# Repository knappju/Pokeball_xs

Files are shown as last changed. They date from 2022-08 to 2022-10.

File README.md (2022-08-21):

# __Pokeball_xs__
## __Project Info__

__Created:__                        August 10, 2022

__Project Version:__                v 0.0.0.2  

__Stable Branch:__                  master

### __Code__
* __IDE:__ MPLAB X IDE v5.50

__Last Release Date:__              August 21, 2022  
__Last Stable Release:__            v 0.0.0.2 

### __ECAD__
* __CAD:__ KiCAD v6.0

__Last Release Date:__              August 21, 2022  
__Last Stable Release:__            v 0.0.0.2

## Versioning

For the versions available, see the [tags on this repository](https://github.com/knappju/Pokeball_xs/commits/master). 
## Authors

* **Justin Knapp** - *Circuit Design, PCB Design, Code, Mechanical Design*

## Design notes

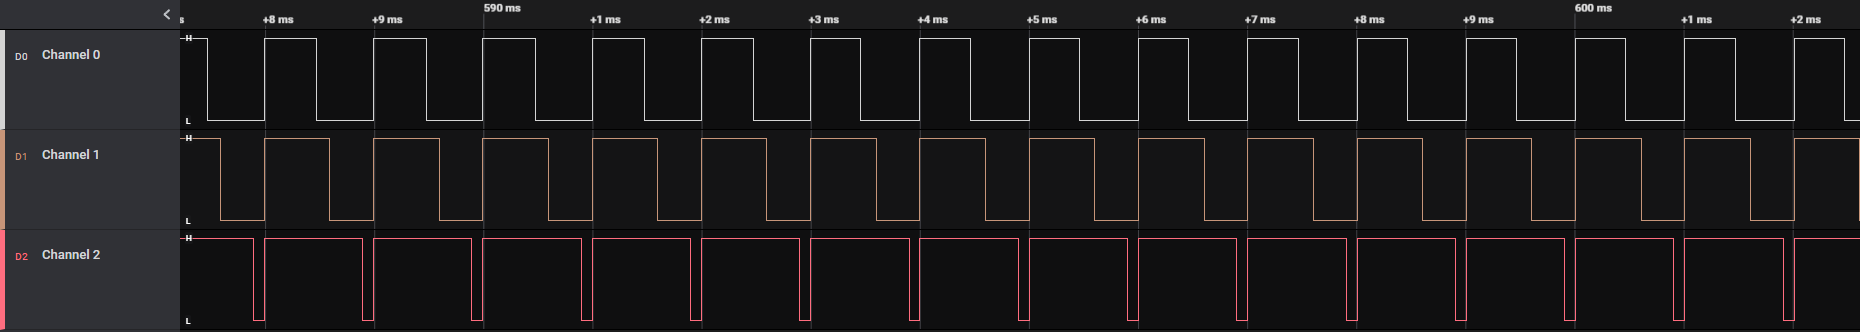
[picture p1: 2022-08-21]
Photos/v0.0.0.2_PWM_proof.PNG

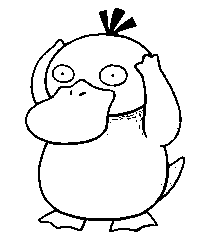
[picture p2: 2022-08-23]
Photos/psyduck.bmp

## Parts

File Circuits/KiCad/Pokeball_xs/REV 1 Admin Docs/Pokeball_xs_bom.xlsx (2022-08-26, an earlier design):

Source: | C:\Users\JustinK\Desktop\Pokeball_xs\Circuits\KiCad\Pokeball_xs\Pokeball_xs.kicad_sch
Date: | 2022-08-25 11:54
Tool: | Eeschema (6.0.5)
Generator: | C:\Program Files\KiCad\6.0\bin\scripting\plugins/bom_csv_grouped_by_value.py
Component Count: | 28
Individual Components:
Item | Qty | Reference(s) | Value | LibPart | Footprint
 |  | C1 | 0.1uF | Pokeball_xs-rescue:CP1_Small-Device | Capacitor_SMD:C_0603_1608Metric
 |  | C2 | 4.7uF | Pokeball_xs-rescue:CP1_Small-Device | Capacitor_SMD:C_0603_1608Metric
 |  | C3 | 0.1uF | Pokeball_xs-rescue:CP1_Small-Device | Capacitor_SMD:C_0603_1608Metric
 |  | C4 | 22uF | Pokeball_xs-rescue:CP1_Small-Device | Capacitor_SMD:C_0603_1608Metric
 |  | C5 | 1uF | Pokeball_xs-rescue:CP1_Small-Device | Capacitor_SMD:C_0603_1608Metric
 |  | C6 | 4.7uF | Pokeball_xs-rescue:CP1_Small-Device | Capacitor_SMD:C_0603_1608Metric
 |  | D1 | 40V 500mA | Device:D_Schottky | Diode_SMD:D_SOD-123
 |  | H1 | MountingHole | Mechanical:MountingHole | MountingHole:MountingHole_4.3mm_M4
 |  | H2 | MountingHole | Mechanical:MountingHole | MountingHole:MountingHole_4.3mm_M4
 |  | H3 | MountingHole | Mechanical:MountingHole | MountingHole:MountingHole_4.3mm_M4
 |  | H4 | MountingHole | Mechanical:MountingHole | MountingHole:MountingHole_4.3mm_M4
 |  | J1 | Conn_01x05 | Connector_Generic:Conn_01x05 | Connector_PinHeader_1.00mm:PinHeader_1x05_P1.00mm_Vertical
 |  | J2 | USB_B_Micro | Connector:USB_B_Micro | Connector_USB:USB_Micro-AB_Molex_47590-0001
 |  | J3 | Conn_01x06 | Connector_Generic:Conn_01x06 | Connector_PinHeader_1.00mm:PinHeader_1x06_P1.00mm_Vertical
 |  | J4 | Battery | Connector:Conn_01x02_Female | Connector_PinSocket_2.54mm:PinSocket_1x02_P2.54mm_Vertical
 |  | Q1 | 60V 170mA | Device:Q_PMOS_GSD | Package_TO_SOT_SMD:TSOT-23
 |  | R1 | 4.7k | Device:R_Small_US | Resistor_SMD:R_0603_1608Metric
 |  | R2 | 100 | Device:R_Small_US | Resistor_SMD:R_0603_1608Metric
 |  | R3 | 56 | Device:R_Small_US | Resistor_SMD:R_0603_1608Metric
 |  | R4 | 24 | Device:R_Small_US | Resistor_SMD:R_0603_1608Metric
 |  | R5 | 24 | Device:R_Small_US | Resistor_SMD:R_0603_1608Metric
 |  | R6 | 100 | Device:R_Small_US | Resistor_SMD:R_0603_1608Metric
 |  | R7 | 4.7k | Device:R_Small_US | Resistor_SMD:R_0603_1608Metric
 |  | R8 | 10k | Device:R_Small_US | Resistor_SMD:R_0603_1608Metric
 |  | R9 | 10k | Device:R_Small_US | Resistor_SMD:R_0603_1608Metric
 |  | U1 | PIC12LF1571T-I_SN | Pokeball_xs-rescue:PIC12LF1571T-I_SN-PIC12LF1571T-I-SN | PIC12LF1571T-I_SN:PIC12LF1571T-I&slash_SN
 |  | U2 | MCP1754ST-3302E_DB | Pokeball_xs-rescue:MCP1754ST-3302E_DB-MCP1754ST-3302E-DB | MCP1754ST-3302E_DB:MCP1754ST-3302E&slash_DB
 |  | U3 | MCP73831-2-OT | Battery_Management:MCP73831-2-OT | Package_TO_SOT_SMD:SOT-23-5
Collated Components:
Item | Qty | Reference(s) | Value | LibPart | Footprint | Cost per 1 | Total Cost | Have? | Ordered | Status
1 | 2 | C1, C3 | 0.1uF | Pokeball_xs-rescue:CP1_Small-Device | Capacitor_SMD:C_0603_1608Metric | 0.0125 | 0.025 | FALSE | TRUE | PENDING
2 | 2 | C2, C6 | 4.7uF | Pokeball_xs-rescue:CP1_Small-Device | Capacitor_SMD:C_0603_1608Metric | 0.0246 | 0.0492 | FALSE | TRUE | PENDING
3 | 1 | C4 | 22uF | Pokeball_xs-rescue:CP1_Small-Device | Capacitor_SMD:C_0603_1608Metric | 0.133 | 0.133 | FALSE | TRUE | PENDING
4 | 1 | C5 | 1uF | Pokeball_xs-rescue:CP1_Small-Device | Capacitor_SMD:C_0603_1608Metric | 0.0146 | 0.0146 | FALSE | TRUE | PENDING
5 | 1 | D1 | 40V 500mA | Device:D_Schottky | Diode_SMD:D_SOD-123 | 0.177 | 0.177 | TRUE | FALSE | GOOD
6 | 4 | H1, H2, H3, H4 | MountingHole | Mechanical:MountingHole | MountingHole:MountingHole_4.3mm_M4 | 0 | 0 | FALSE | FALSE | NEEDS ORDERING
7 | 1 | J1 | Conn_01x05 | Connector_Generic:Conn_01x05 | Connector_PinHeader_1.00mm:PinHeader_1x05_P1.00mm_Vertical | 0 | 0 | FALSE | FALSE | NEEDS ORDERING
8 | 1 | J2 | USB_B_Micro | Connector:USB_B_Micro | Connector_USB:USB_Micro-AB_Molex_47590-0001 | 0.86 | 0.86 | FALSE | TRUE | PENDING
9 | 1 | J3 | Conn_01x06 | Connector_Generic:Conn_01x06 | Connector_PinHeader_1.00mm:PinHeader_1x06_P1.00mm_Vertical | 0 | 0 | FALSE | FALSE | NEEDS ORDERING
10 | 1 | J4 | Battery | Connector:Conn_01x02_Female | Connector_PinSocket_2.54mm:PinSocket_1x02_P2.54mm_Vertical | 0 | 0 | FALSE | FALSE | NEEDS ORDERING
11 | 1 | Q1 | 60V 170mA | Device:Q_PMOS_GSD | Package_TO_SOT_SMD:TSOT-23 | 0.343 | 0.343 | TRUE | FALSE | GOOD
12 | 2 | R1, R7 | 4.7k | Device:R_Small_US | Resistor_SMD:R_0603_1608Metric | 0.0394 | 0.0788 | FALSE | TRUE | PENDING
13 | 2 | R2, R6 | 100 | Device:R_Small_US | Resistor_SMD:R_0603_1608Metric | 0.0184 | 0.0368 | FALSE | TRUE | PENDING
14 | 1 | R3 | 56 | Device:R_Small_US | Resistor_SMD:R_0603_1608Metric | 0.05 | 0.05 | FALSE | TRUE | PENDING
15 | 2 | R4, R5 | 24 | Device:R_Small_US | Resistor_SMD:R_0603_1608Metric | 0.05 | 0.1 | FALSE | TRUE | PENDING
16 | 2 | R8, R9 | 10k | Device:R_Small_US | Resistor_SMD:R_0603_1608Metric | 0.0184 | 0.0368 | FALSE | TRUE | PENDING
17 | 1 | U1 | PIC12LF1571T-I_SN | Pokeball_xs-rescue:PIC12LF1571T-I_SN-PIC12LF1571T-I-SN | PIC12LF1571T-I_SN:PIC12LF1571T-I&slash_SN | 0.79 | 0.79 | TRUE | FALSE | GOOD
18 | 1 | U2 | MCP1754ST-3302E_DB | Pokeball_xs-rescue:MCP1754ST-3302E_DB-MCP1754ST-3302E-DB | MCP1754ST-3302E_DB:MCP1754ST-3302E&slash_DB | 0.84 | 0.84 | TRUE | FALSE | GOOD
19 | 1 | U3 | MCP73831-2-OT | Battery_Management:MCP73831-2-OT | Package_TO_SOT_SMD:SOT-23-5 | 0.76 | 0.76 | TRUE | FALSE | GOOD
 |  |  |  |  |  |  | 4.2942

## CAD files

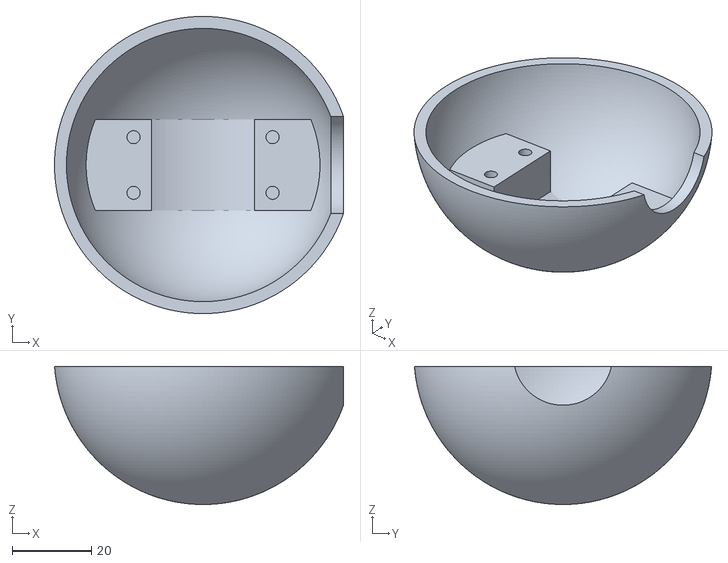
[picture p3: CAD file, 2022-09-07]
Mechanical/Bottom/bottomR1.stl
72.8 x 74.8 x 34.8

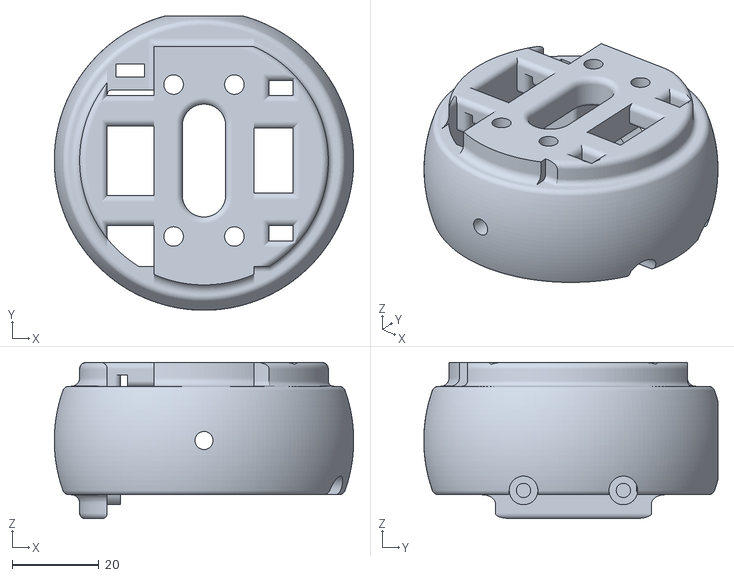
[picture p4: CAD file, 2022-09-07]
Mechanical/CenterHousing/CenterHousingR1.stl
69.0 x 67.7 x 36.0

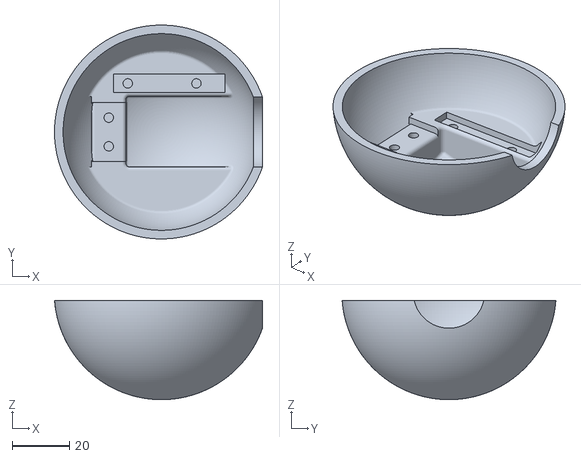
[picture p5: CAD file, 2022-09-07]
Mechanical/Top/top.stl
72.8 x 74.8 x 34.8

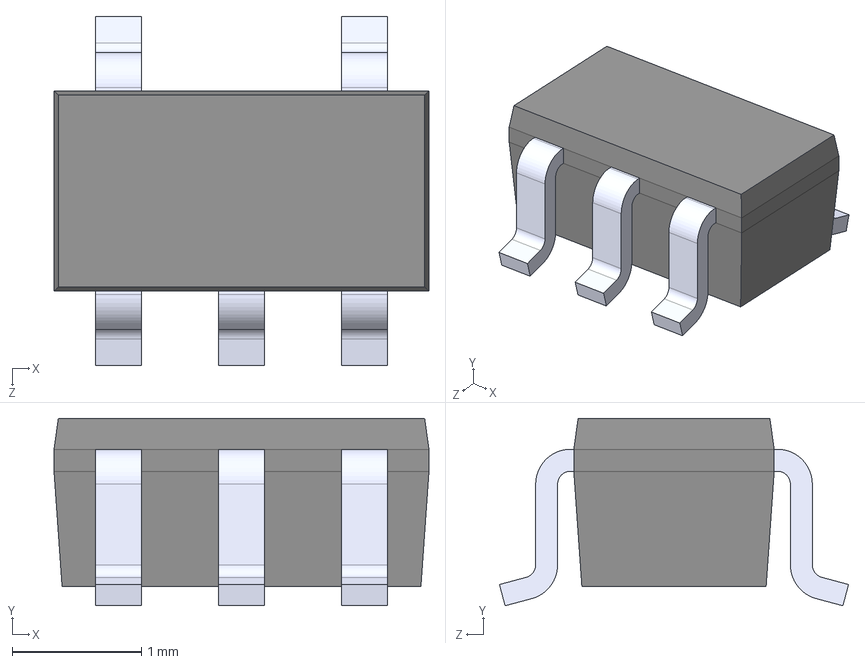
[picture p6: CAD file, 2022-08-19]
Circuits/Part Libraries/MCP73831T-2ACI_OT/MCP73831T-2ACI_OT.step
2.90 x 1.45 x 2.70 mm

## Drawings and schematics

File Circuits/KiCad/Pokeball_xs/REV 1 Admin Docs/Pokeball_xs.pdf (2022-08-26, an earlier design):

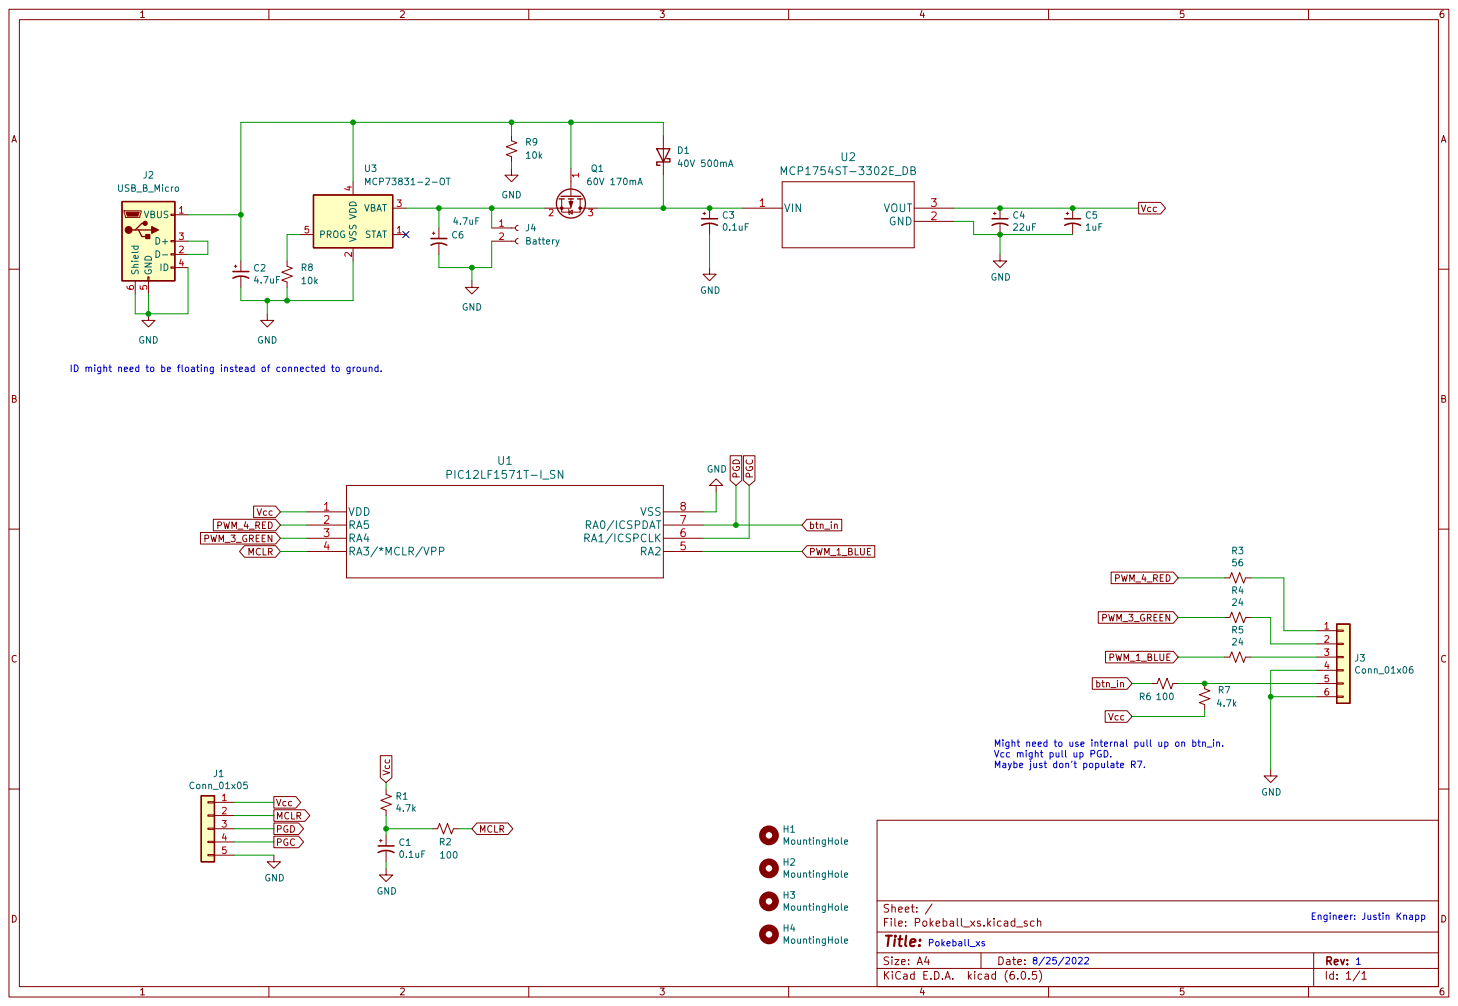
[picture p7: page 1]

ID might need to be floating instead of connected to ground.

8/25/2022 Might need to use internal pull up on btn_in.
Vcc might pull up PGD.

Maybe just don't populate R7. Pokeball_xs

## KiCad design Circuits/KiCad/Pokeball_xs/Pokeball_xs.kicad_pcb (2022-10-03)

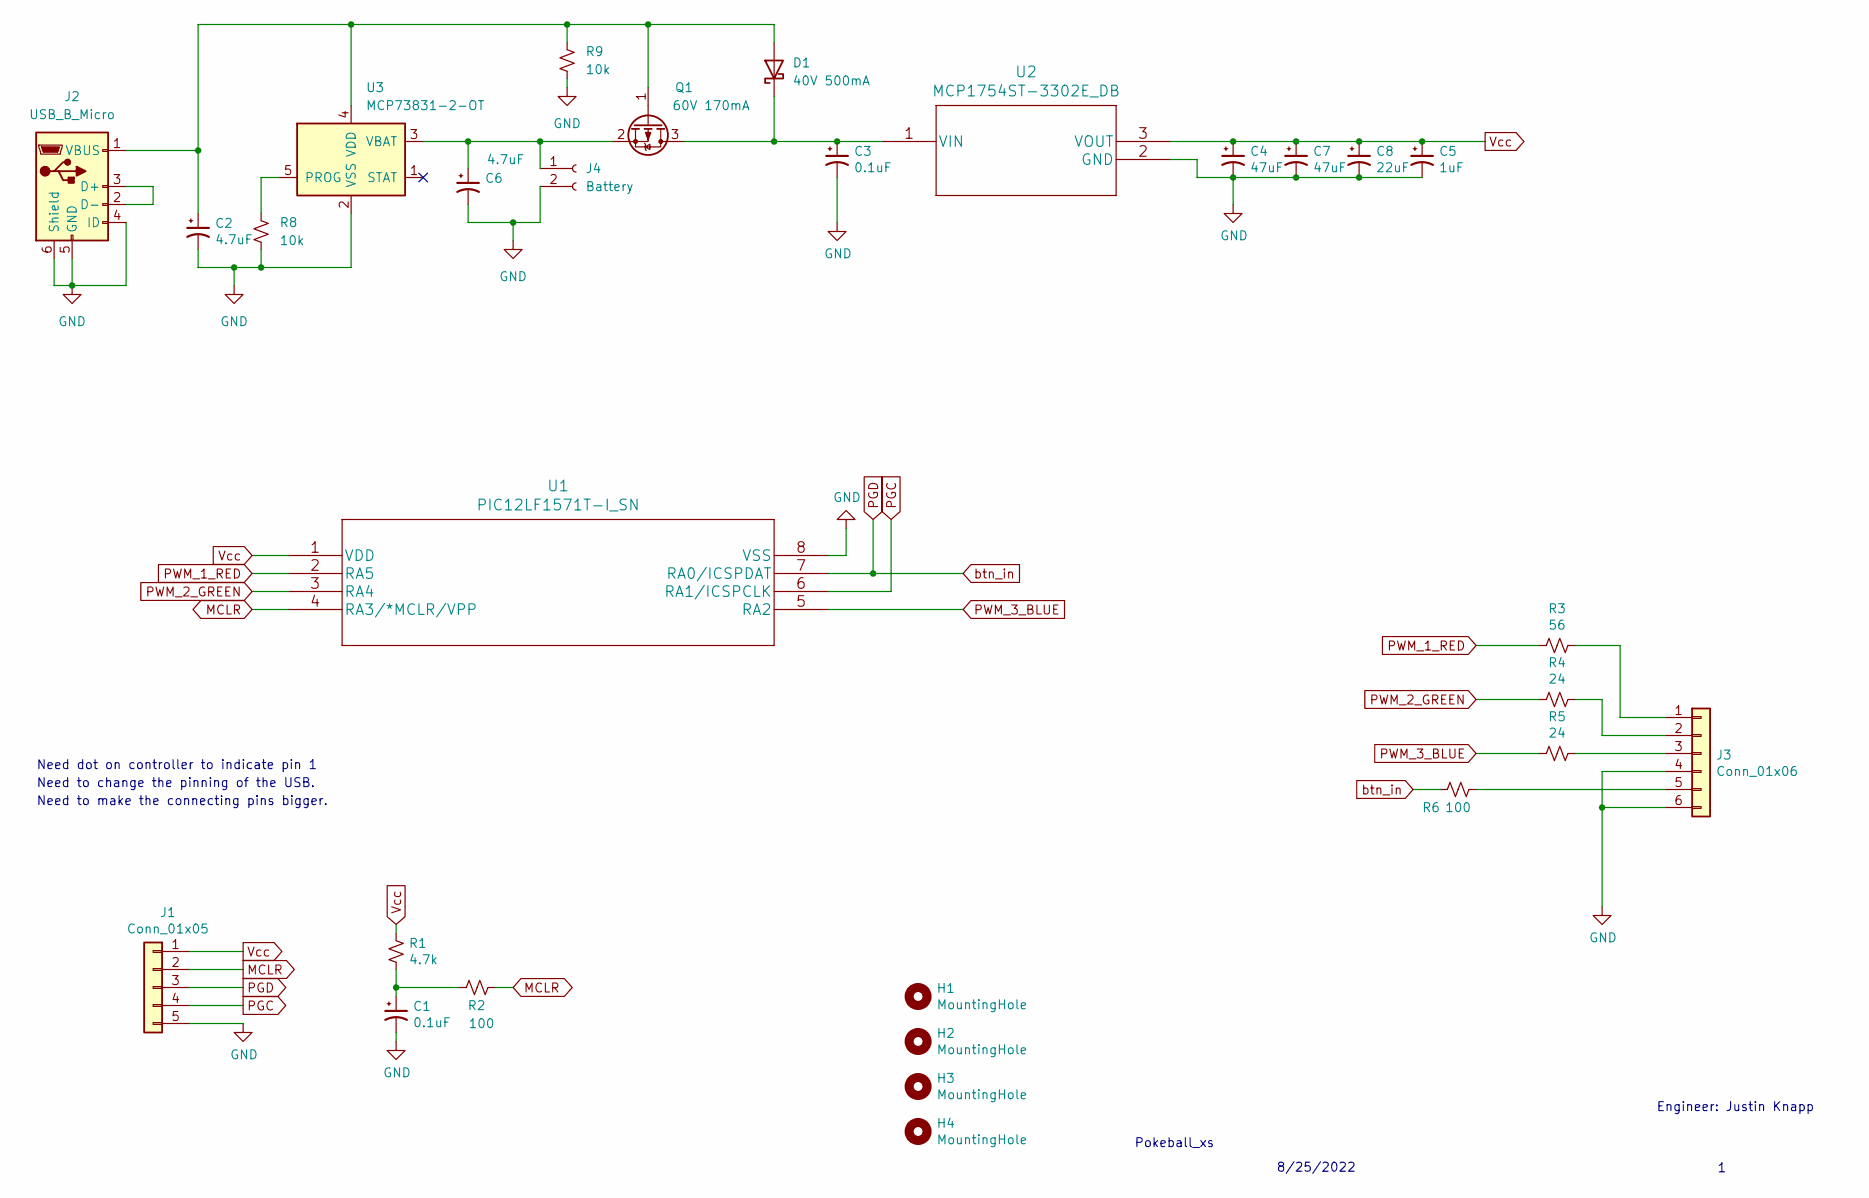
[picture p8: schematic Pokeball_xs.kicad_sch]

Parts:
C1, C3: 0.1uF; C_0603_1608Metric
C2, C6: 4.7uF; C_0603_1608Metric
C4, C7: 47uF; C_0603_1608Metric
C5: 1uF; C_0603_1608Metric
C8: 22uF; C_0603_1608Metric
D1: 40V 500mA; D_SOD-123
H1, H2, H3, H4: MountingHole; MountingHole_4.3mm_M4
J1: Conn_01x05; PinHeader_1x05_P2.00mm_Vertical
J2: USB_B_Micro; USB_Micro-B_Molex-105017-0001
J3: Conn_01x06; PinHeader_1x06_P2.00mm_Vertical
J4: Battery; PinSocket_1x02_P2.54mm_Vertical
Q1: 60V 170mA; TSOT-23
R1: 4.7k; R_0603_1608Metric
R2, R6: 100; R_0603_1608Metric
R3: 56; R_0603_1608Metric
R4, R5: 24; R_0603_1608Metric
R8, R9: 10k; R_0603_1608Metric
U1: PIC12LF1571T-I_SN; PIC12LF1571T-I&slash_SN
U2: MCP1754ST-3302E_DB; MCP1754ST-3302E&slash_DB
U3: MCP73831-2-OT; SOT-23-5

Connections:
GND: C1.2, C2.2, C3.2, C4.2, C5.2, C6.2, C7.2, C8.2, J1.5, J2.4 (ID), J2.5 (GND), J2.6 (Shield), J3.4, J3.6, J4.2, R8.2, R9.2, U1.8 (VSS), U2.2 (GND), U3.2 (VSS)
MCLR: J1.2, R2.2, U1.4 (RA3/*MCLR/VPP)
unnamed: C1.1, R1.2, R2.1
unnamed: C2.1, D1.2 (A), J2.1 (VBUS), Q1.1 (G), R9.1, U3.4 (VDD)
unnamed: C3.1, D1.1 (K), Q1.3 (D), U2.1 (VIN)
unnamed: C6.1, J4.1, Q1.2 (S), U3.3 (VBAT)
unnamed: J2.2 (D-), J2.3 (D+)
unnamed: J3.1, R3.1
unnamed: J3.2, R4.1
unnamed: J3.3, R5.1
unnamed: J3.5, R6.1
unnamed: R8.1, U3.5 (PROG)
PGC: J1.4, U1.6 (RA1/ICSPCLK)
PGD: J1.3, R6.2, U1.7 (RA0/ICSPDAT)
PWM_1_RED: R3.2, U1.2 (RA5)
PWM_2_GREEN: R4.2, U1.3 (RA4)
PWM_3_BLUE: R5.2, U1.5 (RA2)
Vcc: C4.1, C5.1, C7.1, C8.1, J1.1, R1.1, U1.1 (VDD), U2.3 (VOUT)

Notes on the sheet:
8/25/2022
Need to change the pinning of the USB.
Need dot on controller to indicate pin 1
Pokeball_xs
Need to make the connecting pins bigger.
Engineer: Justin Knapp

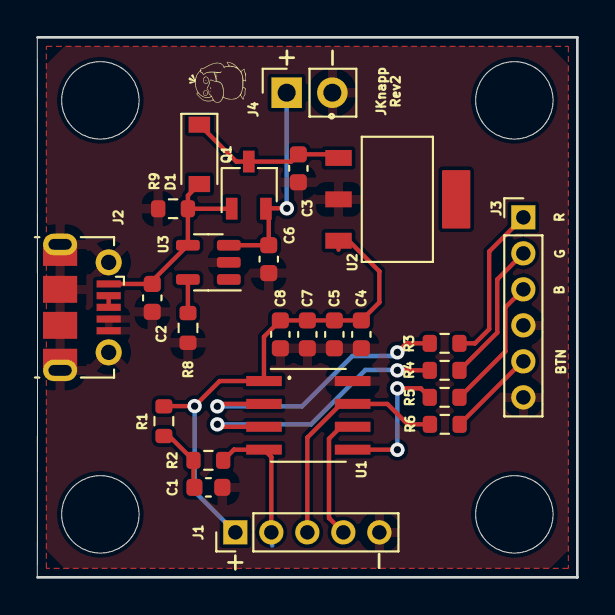
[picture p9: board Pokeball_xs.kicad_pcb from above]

Board: 2 copper layers, 30.0 x 30.0 mm, 29 parts (0 on the bottom side), 18 nets.

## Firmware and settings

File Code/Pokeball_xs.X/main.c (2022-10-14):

/**
  Generated Main Source File

  Company:
    Microchip Technology Inc.

  File Name:
    main.c

  Summary:
    This is the main file generated using PIC10 / PIC12 / PIC16 / PIC18 MCUs

  Description:
    This header file provides implementations for driver APIs for all modules selected in the GUI.
    Generation Information :
        Product Revision  :  PIC10 / PIC12 / PIC16 / PIC18 MCUs - 1.81.7
        Device            :  PIC12LF1571
        Driver Version    :  2.00
*/

/*
    (c) 2018 Microchip Technology Inc. and its subsidiaries. 
    
    Subject to your compliance with these terms, you may use Microchip software and any 
    derivatives exclusively with Microchip products. It is your responsibility to comply with third party 
    license terms applicable to your use of third party software (including open source software) that 
    may accompany Microchip software.
    
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
    IN NO EVENT WILL MICROCHIP BE LIABLE FOR ANY INDIRECT, SPECIAL, PUNITIVE, 
    INCIDENTAL OR CONSEQUENTIAL LOSS, DAMAGE, COST OR EXPENSE OF ANY KIND 
    WHATSOEVER RELATED TO THE SOFTWARE, HOWEVER CAUSED, EVEN IF MICROCHIP 
    HAS BEEN ADVISED OF THE POSSIBILITY OR THE DAMAGES ARE FORESEEABLE. TO 
    THE FULLEST EXTENT ALLOWED BY LAW, MICROCHIP'S TOTAL LIABILITY ON ALL 
    CLAIMS IN ANY WAY RELATED TO THIS SOFTWARE WILL NOT EXCEED THE AMOUNT 
    OF FEES, IF ANY, THAT YOU HAVE PAID DIRECTLY TO MICROCHIP FOR THIS 
    SOFTWARE.
*/

#include "mcc_generated_files/mcc.h"
#include "main.h"

// Local variables
enum state{INIT, SLEEP, READY_TO_ENTER_BUTTON, WAIT_FOR_BUTTON, BLINKING, CAUGHT, NOT_CAUGHT};

enum state currentState = INIT;

uint8_t randCounter = 0;

DEBOUNCEbits_t DEBOUNCEbits;
ACTIONbits_t ACTIONbits;

void main(void)
{
    // initialize the device
    SYSTEM_Initialize();
    
    //start timer 2
    T2CONbits.TMR2ON = 1;

    // Enable the Global Interrupts
    INTERRUPT_GlobalInterruptEnable();

    // Enable the Peripheral Interrupts
    INTERRUPT_PeripheralInterruptEnable();
    
    while (1)
    {
        
        /*debounce the button. every 6 ms, the buttons value is shifted into 
         * DEBOUNCEbits.debounceBuffer. The buffer is 5 bits. This means that
         * a complete debounce cycle happens every 30 ms. */
        if(DEBOUNCEbits.btnTicks >= 6){
            DEBOUNCEbits.btnTicks = 0;
            DEBOUNCEbits.debounceBuffer = (DEBOUNCEbits.debounceBuffer << 1 ) | !PORTAbits.RA0;
        }

        switch(currentState){
            case INIT:
                currentState = WAIT_FOR_BUTTON;
                setColors(3500,3500,3500,0);
                timeInState = 0;
                break;
            case SLEEP:
                if(DEBOUNCEbits.debounceBuffer == 0x1F){
                    currentState = READY_TO_ENTER_BUTTON;
                    timeInState = 0;
                }
                break; 
            case READY_TO_ENTER_BUTTON:
                if(DEBOUNCEbits.debounceBuffer == 0x00){
                    currentState = WAIT_FOR_BUTTON;
                    setColors(3500,3500,3500,0);
                    timeInState = 0;
                }
                break;
            case WAIT_FOR_BUTTON:
                if(timeInState >= SLEEP_TIME){
                    setColors(0,0,0,0);
                    currentState = SLEEP;
                    timeInState = 0;
                }
                if(DEBOUNCEbits.debounceBuffer == 0x1F){
                    ACTIONbits.fade = 0;
                    ACTIONbits.direction = 0;
                    ACTIONbits.currentBlinks = 0;
                    ACTIONbits.numOfBlinks = ((randCounter >> 5) & 0x03) + 1;
                    ACTIONbits.isCaught = ((randCounter >> 4) & 0x01);
                    currentState = BLINKING;
                    timeInState = 0;
                }
                break;
            case BLINKING:
                if(timeInState >= 25){
                    if(ACTIONbits.direction == UP){
                        ACTIONbits.fade += 5;
                        if(ACTIONbits.fade >= 140){
                            ACTIONbits.direction = DOWN;
                        }
                    }
                    else{
                        ACTIONbits.fade -= 5;
                        if(ACTIONbits.fade <= 15){
                            ACTIONbits.direction = UP;
                            ACTIONbits.currentBlinks++;
                        }
                    } 
                    timeInState = 0;
                    setColors(65535,0,0,ACTIONbits.fade);
                }
                if(ACTIONbits.currentBlinks == ACTIONbits.numOfBlinks){
                    if(ACTIONbits.isCaught){
                        ACTIONbits.fade = 0;
                        ACTIONbits.direction = 0;
                        ACTIONbits.currentBlinks = 0;
                        currentState = CAUGHT;
                        timeInState = 0;
                    }
                    else{
                        setColors(0,0,0,0);
                        currentState = NOT_CAUGHT;
                        timeInState = 0;
                    }
                }
                break;
            case CAUGHT:
                if(timeInState >= 20){
                    if(ACTIONbits.direction == UP){
                        ACTIONbits.fade += 30;
                        timeInState = 0;
                        if(ACTIONbits.fade >= 220){
                            ACTIONbits.direction = DOWN;
                        }
                        setColors(65535,65535,65535,ACTIONbits.fade);
                    }
                    else{
                        if(ACTIONbits.fade > 100){
                            ACTIONbits.fade -= 15;
                            timeInState = 0;
                            setColors(65535,65535,65535,ACTIONbits.fade);
                        }
                    }
                }
                if(timeInState == CAUGHT_TIME){
                    currentState = READY_TO_ENTER_BUTTON;
                    setColors(3500,3500,3500,0);
                    timeInState = 0;
                }
                break;
            case NOT_CAUGHT:
                if(timeInState == NOT_CAUGHT_TIME){
                    currentState = READY_TO_ENTER_BUTTON;
                    setColors(3500,3500,3500,0);
                    timeInState = 0;
                }
                break;
            default:
                currentState = INIT;
                timeInState = 0;
                break;
        }
    }
}

void msTick(){
    DEBOUNCEbits.btnTicks++;
    randCounter++;
    timeInState++;
}

void setColors(uint16_t r, uint16_t g, uint16_t b, uint8_t fade){
    
    if(fade > 0){
        r = r >> 8; //make an 8 bit version of the number
        r = r * fade; // create the new version
        g = g >> 8; //make an 8 bit version of the number
        g = g * fade; // create the new version
        b = b >> 8; //make an 8 bit version of the number
        b = b * fade; // create the new version
    }
    
    PWM1CONbits.EN = 0;	
    PWM1DCH = (r>>8);	//writing 8 MSBs to PWMDCH register
    PWM1DCL = (r);
    PWM1CONbits.EN = 1;	
    
    PWM2CONbits.EN = 0;	
    PWM2DCH = (g>>8);	//writing 8 MSBs to PWMDCH register
    PWM2DCL = (g);
    PWM2CONbits.EN = 1;	
    
    PWM3CONbits.EN = 0;	
    PWM3DCH = (b>>8);	//writing 8 MSBs to PWMDCH register
    PWM3DCL = (b);
    PWM3CONbits.EN = 1;	
}
/**
 End of File
*/

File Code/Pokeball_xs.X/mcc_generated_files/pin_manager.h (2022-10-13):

/**
  @Generated Pin Manager Header File

  @Company:
    Microchip Technology Inc.

  @File Name:
    pin_manager.h

  @Summary:
    This is the Pin Manager file generated using PIC10 / PIC12 / PIC16 / PIC18 MCUs

  @Description
    This header file provides APIs for driver for .
    Generation Information :
        Product Revision  :  PIC10 / PIC12 / PIC16 / PIC18 MCUs - 1.81.7
        Device            :  PIC12LF1571
        Driver Version    :  2.11
    The generated drivers are tested against the following:
        Compiler          :  XC8 2.31 and above
        MPLAB 	          :  MPLAB X 5.45	
*/

/*
    (c) 2018 Microchip Technology Inc. and its subsidiaries. 
    
    Subject to your compliance with these terms, you may use Microchip software and any 
    derivatives exclusively with Microchip products. It is your responsibility to comply with third party 
    license terms applicable to your use of third party software (including open source software) that 
    may accompany Microchip software.
    
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
    IN NO EVENT WILL MICROCHIP BE LIABLE FOR ANY INDIRECT, SPECIAL, PUNITIVE, 
    INCIDENTAL OR CONSEQUENTIAL LOSS, DAMAGE, COST OR EXPENSE OF ANY KIND 
    WHATSOEVER RELATED TO THE SOFTWARE, HOWEVER CAUSED, EVEN IF MICROCHIP 
    HAS BEEN ADVISED OF THE POSSIBILITY OR THE DAMAGES ARE FORESEEABLE. TO 
    THE FULLEST EXTENT ALLOWED BY LAW, MICROCHIP'S TOTAL LIABILITY ON ALL 
    CLAIMS IN ANY WAY RELATED TO THIS SOFTWARE WILL NOT EXCEED THE AMOUNT 
    OF FEES, IF ANY, THAT YOU HAVE PAID DIRECTLY TO MICROCHIP FOR THIS 
    SOFTWARE.
*/

#ifndef PIN_MANAGER_H
#define PIN_MANAGER_H

/**
  Section: Included Files
*/

#include <xc.h>

#define INPUT   1
#define OUTPUT  0

#define HIGH    1
#define LOW     0

#define ANALOG      1
#define DIGITAL     0

#define PULL_UP_ENABLED      1
#define PULL_UP_DISABLED     0

// get/set BTN_IN aliases
#define BTN_IN_TRIS                 TRISAbits.TRISA0
#define BTN_IN_LAT                  LATAbits.LATA0
#define BTN_IN_PORT                 PORTAbits.RA0
#define BTN_IN_WPU                  WPUAbits.WPUA0
#define BTN_IN_OD                   ODCONAbits.ODA0
#define BTN_IN_ANS                  ANSELAbits.ANSA0
#define BTN_IN_SetHigh()            do { LATAbits.LATA0 = 1; } while(0)
#define BTN_IN_SetLow()             do { LATAbits.LATA0 = 0; } while(0)
#define BTN_IN_Toggle()             do { LATAbits.LATA0 = ~LATAbits.LATA0; } while(0)
#define BTN_IN_GetValue()           PORTAbits.RA0
#define BTN_IN_SetDigitalInput()    do { TRISAbits.TRISA0 = 1; } while(0)
#define BTN_IN_SetDigitalOutput()   do { TRISAbits.TRISA0 = 0; } while(0)
#define BTN_IN_SetPullup()          do { WPUAbits.WPUA0 = 1; } while(0)
#define BTN_IN_ResetPullup()        do { WPUAbits.WPUA0 = 0; } while(0)
#define BTN_IN_SetPushPull()        do { ODCONAbits.ODA0 = 0; } while(0)
#define BTN_IN_SetOpenDrain()       do { ODCONAbits.ODA0 = 1; } while(0)
#define BTN_IN_SetAnalogMode()      do { ANSELAbits.ANSA0 = 1; } while(0)
#define BTN_IN_SetDigitalMode()     do { ANSELAbits.ANSA0 = 0; } while(0)

// get/set RA2 procedures
#define RA2_SetHigh()            do { LATAbits.LATA2 = 1; } while(0)
#define RA2_SetLow()             do { LATAbits.LATA2 = 0; } while(0)
#define RA2_Toggle()             do { LATAbits.LATA2 = ~LATAbits.LATA2; } while(0)
#define RA2_GetValue()              PORTAbits.RA2
#define RA2_SetDigitalInput()    do { TRISAbits.TRISA2 = 1; } while(0)
#define RA2_SetDigitalOutput()   do { TRISAbits.TRISA2 = 0; } while(0)
#define RA2_SetPullup()             do { WPUAbits.WPUA2 = 1; } while(0)
#define RA2_ResetPullup()           do { WPUAbits.WPUA2 = 0; } while(0)
#define RA2_SetAnalogMode()         do { ANSELAbits.ANSA2 = 1; } while(0)
#define RA2_SetDigitalMode()        do { ANSELAbits.ANSA2 = 0; } while(0)

// get/set RA4 procedures
#define RA4_SetHigh()            do { LATAbits.LATA4 = 1; } while(0)
#define RA4_SetLow()             do { LATAbits.LATA4 = 0; } while(0)
#define RA4_Toggle()             do { LATAbits.LATA4 = ~LATAbits.LATA4; } while(0)
#define RA4_GetValue()              PORTAbits.RA4
#define RA4_SetDigitalInput()    do { TRISAbits.TRISA4 = 1; } while(0)
#define RA4_SetDigitalOutput()   do { TRISAbits.TRISA4 = 0; } while(0)
#define RA4_SetPullup()             do { WPUAbits.WPUA4 = 1; } while(0)
#define RA4_ResetPullup()           do { WPUAbits.WPUA4 = 0; } while(0)
#define RA4_SetAnalogMode()         do { ANSELAbits.ANSA4 = 1; } while(0)
#define RA4_SetDigitalMode()        do { ANSELAbits.ANSA4 = 0; } while(0)

// get/set RA5 procedures
#define RA5_SetHigh()            do { LATAbits.LATA5 = 1; } while(0)
#define RA5_SetLow()             do { LATAbits.LATA5 = 0; } while(0)
#define RA5_Toggle()             do { LATAbits.LATA5 = ~LATAbits.LATA5; } while(0)
#define RA5_GetValue()              PORTAbits.RA5
#define RA5_SetDigitalInput()    do { TRISAbits.TRISA5 = 1; } while(0)
#define RA5_SetDigitalOutput()   do { TRISAbits.TRISA5 = 0; } while(0)
#define RA5_SetPullup()             do { WPUAbits.WPUA5 = 1; } while(0)
#define RA5_ResetPullup()           do { WPUAbits.WPUA5 = 0; } while(0)

/**
   @Param
    none
   @Returns
    none
   @Description
    GPIO and peripheral I/O initialization
   @Example
    PIN_MANAGER_Initialize();
 */
void PIN_MANAGER_Initialize (void);

/**
 * @Param
    none
 * @Returns
    none
 * @Description
    Interrupt on Change Handling routine
 * @Example
    PIN_MANAGER_IOC();
 */
void PIN_MANAGER_IOC(void);



#endif // PIN_MANAGER_H
/**
 End of File
*/

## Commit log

2022-08-10 v 0.0.0.0 - init project commit
    [Pokeball_xs.kicad_pcb, Pokeball_xs.kicad_sch, Pokeball_xs.sch]
2022-08-19 v 0.0.0.1 - Include the charging circuit on the PCB
    [MCP73831T-2ACI_OT.step, Pokeball_xs.kicad_pcb, Pokeball_xs.kicad_sch]
2022-08-21 v 0.0.0.2 - Testing the pwm output on the switch. Creation of the README.md.
    [Pokeball_xs.kicad_pcb, Pokeball_xs.kicad_sch, Pokeball_xs.sch]
2022-08-23 v 0.0.0.3 - updates to the board and the mechanical system.
    [Pokeball_xs.kicad_pcb, Pokeball_xs.kicad_sch]
2022-08-24 v 0.0.0.4 - submit rev 1 of the pokeball to pcbway.
    [Pokeball_xs.kicad_pcb]
2022-08-26 v 0.0.0.5 - updates to some circuit admin stuff
    [Pokeball_xs.kicad_sch, Pokeball_xs_bom.xlsx]
2022-09-07 v 0.0.0.6 - Testing the circuit
    [Pokeball_xs.kicad_pcb, Pokeball_xs.kicad_sch]
2022-09-07 v 0.0.0.7 - add the mechanical
    [CenterHousingR1.stl, bottomR1.stl, top.stl]
2022-10-03 v 0.0.0.8 - Board submitted to pcbway
    [Pokeball_xs-B_Cu.gbl, Pokeball_xs-B_Mask.gbs, Pokeball_xs-B_Paste.gbp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]

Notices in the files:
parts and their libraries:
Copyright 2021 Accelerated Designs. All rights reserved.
